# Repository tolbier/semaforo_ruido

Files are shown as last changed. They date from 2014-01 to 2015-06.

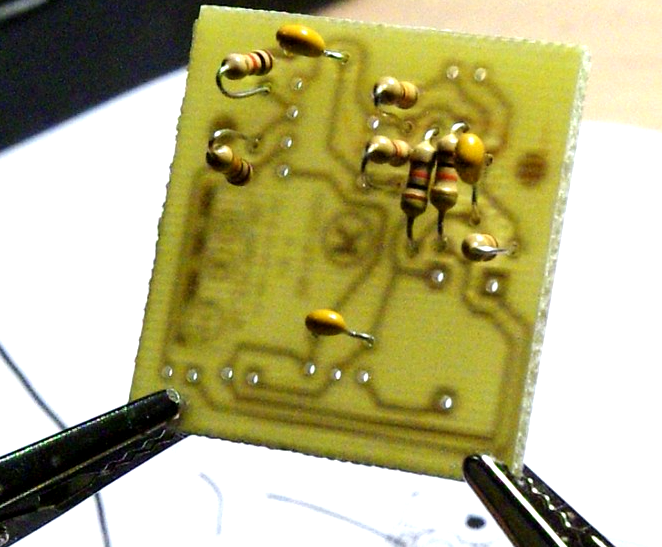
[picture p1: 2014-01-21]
tutoriales/images/wired_sensor_PCB_images/step12.png

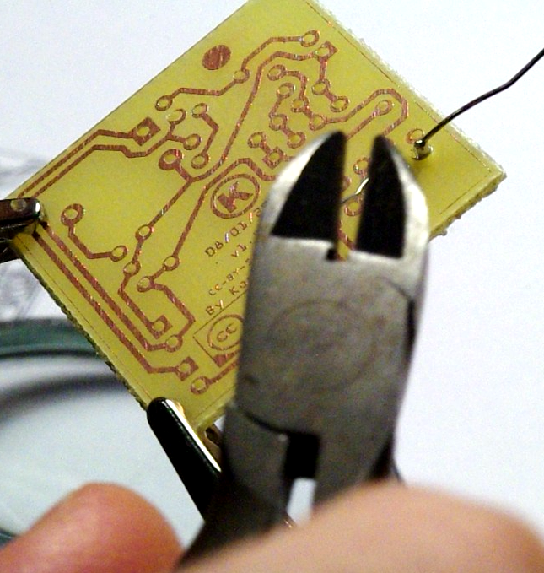
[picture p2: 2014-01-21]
tutoriales/images/wired_sensor_PCB_images/step6.png

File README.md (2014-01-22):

**para encontrar  ayuda y documentación, visita la [Wiki del proyecto](https://github.com/tolbier/semaforo_ruido/wiki)**

Semáforo de Ruido OpenSource
============================
El Semáforo de Ruido "OpenSource" es una instalación que capta el ruido de ambiente y activa un juego de 4 bloques de luces LED (en Verde, Amarillo, Naranja y Rojo) indicando la cantidad de ruido que hay en el ambiente.

Asimismo, se puede conectar un [MP3 Player Shield de SPARKFUN](https://www.sparkfun.com/products/10628), para reproducir sonidos al llegar a determinados niveles de ruido.



Un Proyecto Educativo
---------------------
Este proyecto tiene la aspiración de servir como herramienta educativa, con 2 funciones distintas:
* Servir como apoyo a los equipos docentes de los centros educativos en su tarea de lograr un espacio educativo libre de contaminación acústica.
* Como proyecto educativo en el área de Tecnología, que permite lograr conocimientos en las áreas de Electrónica y Programación Informática.

Licencia
--------
Los [esquemas y diseños PCB de las placas](https://github.com/tolbier/semaforo_ruido/tree/master/PCBs) están licenciados bajo [CC-BY-SA 3.0](http://creativecommons.org/licenses/by-sa/3.0/es/)

El [software](https://github.com/tolbier/semaforo_ruido/tree/master/src) está licenciado bajo [GNU/GPL v3.0](https://github.com/tolbier/semaforo_ruido/blob/master/src/LICENSE.txt)

Los [sonidos](https://github.com/tolbier/semaforo_ruido/tree/master/sonidos) incluídos en este proyecto están licenciados bajo [CC-BY-SA 3.0](http://creativecommons.org/licenses/by-sa/3.0/es/)

Todos los textos incluídos en este proyecto están licenciados bajo [CC-BY-SA 3.0](http://creativecommons.org/licenses/by-sa/3.0/es/)

**para encontrar  ayuda y documentación, visita la [Wiki del proyecto](https://github.com/tolbier/semaforo_ruido/wiki)**

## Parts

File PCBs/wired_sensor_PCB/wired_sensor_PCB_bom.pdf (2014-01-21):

# Bill of Materials: wired_sensor_PCB.fzz

/home/toyos/gitroot/semaforo_ruido_github/PCBs/wired_sensor_PCB/wired_sensor_PCB.fzz
martes, enero 21 2014, 22:05:40

# Assembly List

Label | Part Type | Properties
C1 | Ceramic Capacitor | paquete 200 mil [THT, multilayer]; capacitance 0.1µF; Voltaje 6.3V; part number 0.1uF
C2 | Electrolytic Capacitor | paquete 100 mil [THT, electrolytic]; capacitance 4.7µF; Voltaje 6.3V; part number 4.7uF
C3 | Electrolytic Capacitor | paquete 100 mil [THT, electrolytic]; capacitance 4.7µF; Voltaje 6.3V; part number 4.7uF
C4 | Ceramic Capacitor | paquete 200 mil [THT, multilayer]; capacitance 0.1µF; Voltaje 6.3V; part number 0.1uF
C5 | Ceramic Capacitor | paquete 200 mil [THT, multilayer]; capacitance 0.1µF; Voltaje 6.3V; part number 0.1uF
J1 | Generic male header - 3 pins | paquete THT; Tamaño del hoyo 0.8mm,0.5mm; row single; forma ♂ (male); pins 3; espacio entre pines 0.1in (2.54mm)
LM358 | LM 358 Dual Op-Amp | paquete DIP8 [THT]; part number LM358
MIC1 | Microphone
R1 | 1k Ω Resistor | paquete THT; tolerance ±5%; bands 4; Resistencia 1kΩ; power 250mW; espacio entre pines 400 mil; part number 1kΩ
Fritzing Bill of Materials | file:///usr2/gitroot/semaforo_ruido_github/PCBs/wired_sensor_PCB/...
1 de 3 | 21/01/14 22:28

Label | Part Type | Properties
R2 | 10k Ω Resistor | paquete THT; tolerance ±5%; bands 4; Resistencia 10kΩ; power 250mW; espacio entre pines 400 mil; part number 10K
R3 | 10k Ω Resistor | paquete THT; tolerance ±5%; bands 4; Resistencia 10kΩ; power 250mW; espacio entre pines 400 mil; part number 10K
R4 | 10k Ω Resistor | paquete THT; tolerance ±5%; bands 4; Resistencia 10kΩ; power 250mW; espacio entre pines 400 mil; part number 10K
R5 | 1k Ω Resistor | paquete THT; tolerance ±5%; bands 4; Resistencia 1kΩ; power 250mW; espacio entre pines 400 mil; part number 1kΩ
R6 | 10k Ω Resistor | paquete THT; tolerance ±5%; bands 4; Resistencia 10kΩ; power 250mW; espacio entre pines 400 mil; part number 10K
R7 | 10k Ω Resistor | paquete THT; tolerance ±5%; bands 4; Resistencia 10kΩ; power 250mW; espacio entre pines 400 mil; part number 10K
R8 | Trimmer Potentiometer | paquete THT; tamaño Trimmer - 12mm; track Linear; Tipo Trimmer Potentiometer; power 0.25W; máxima resistencia 5kΩ; part number 5kΩ

# Shopping List

Amount | Part Type | Properties
3 | Ceramic Capacitor | paquete 200 mil [THT, multilayer]; capacitance 0.1µF; Voltaje 6.3V; part number 0.1uF
2 | Electrolytic Capacitor | paquete 100 mil [THT, electrolytic]; capacitance 4.7µF; Voltaje 6.3V; part number 4.7uF
1 | Generic male header - 3 pins | paquete THT; Tamaño del hoyo 0.8mm,0.5mm; row single; forma ♂ (male); pins 3; espacio entre pines 0.1in (2.54mm)
1 | LM 358 Dual Op-Amp | paquete DIP8 [THT]; part number LM358

Amount | Part Type | Properties
1 | Microphone
2 | 1k Ω Resistor | paquete THT; tolerance ±5%; bands 4; Resistencia 1kΩ; power 250mW; espacio entre pines 400 mil; part number 1kΩ
5 | 10k Ω Resistor | paquete THT; tolerance ±5%; bands 4; Resistencia 10kΩ; power 250mW; espacio entre pines 400 mil; part number 10K
1 | Trimmer Potentiometer | paquete THT; tamaño Trimmer - 12mm; track Linear; Tipo Trimmer Potentiometer; power 0.25W; máxima resistencia 5kΩ; part number 5kΩ

Exported with Fritzing 0.8.5- http://fritzing.org

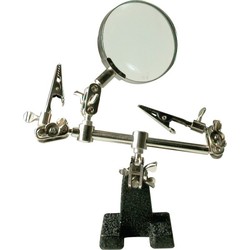
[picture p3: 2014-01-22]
tutoriales/images/material_necesario/soporte-lupa-pcb.jpg

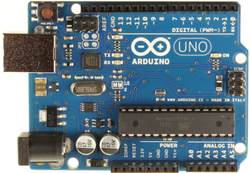
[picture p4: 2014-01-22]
tutoriales/images/material_necesario/ArduinoUno_R3.jpg

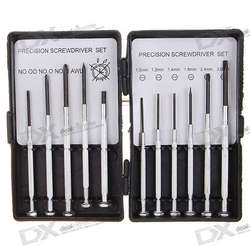
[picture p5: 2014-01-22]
tutoriales/images/material_necesario/juego_destornilladores_precision.jpg

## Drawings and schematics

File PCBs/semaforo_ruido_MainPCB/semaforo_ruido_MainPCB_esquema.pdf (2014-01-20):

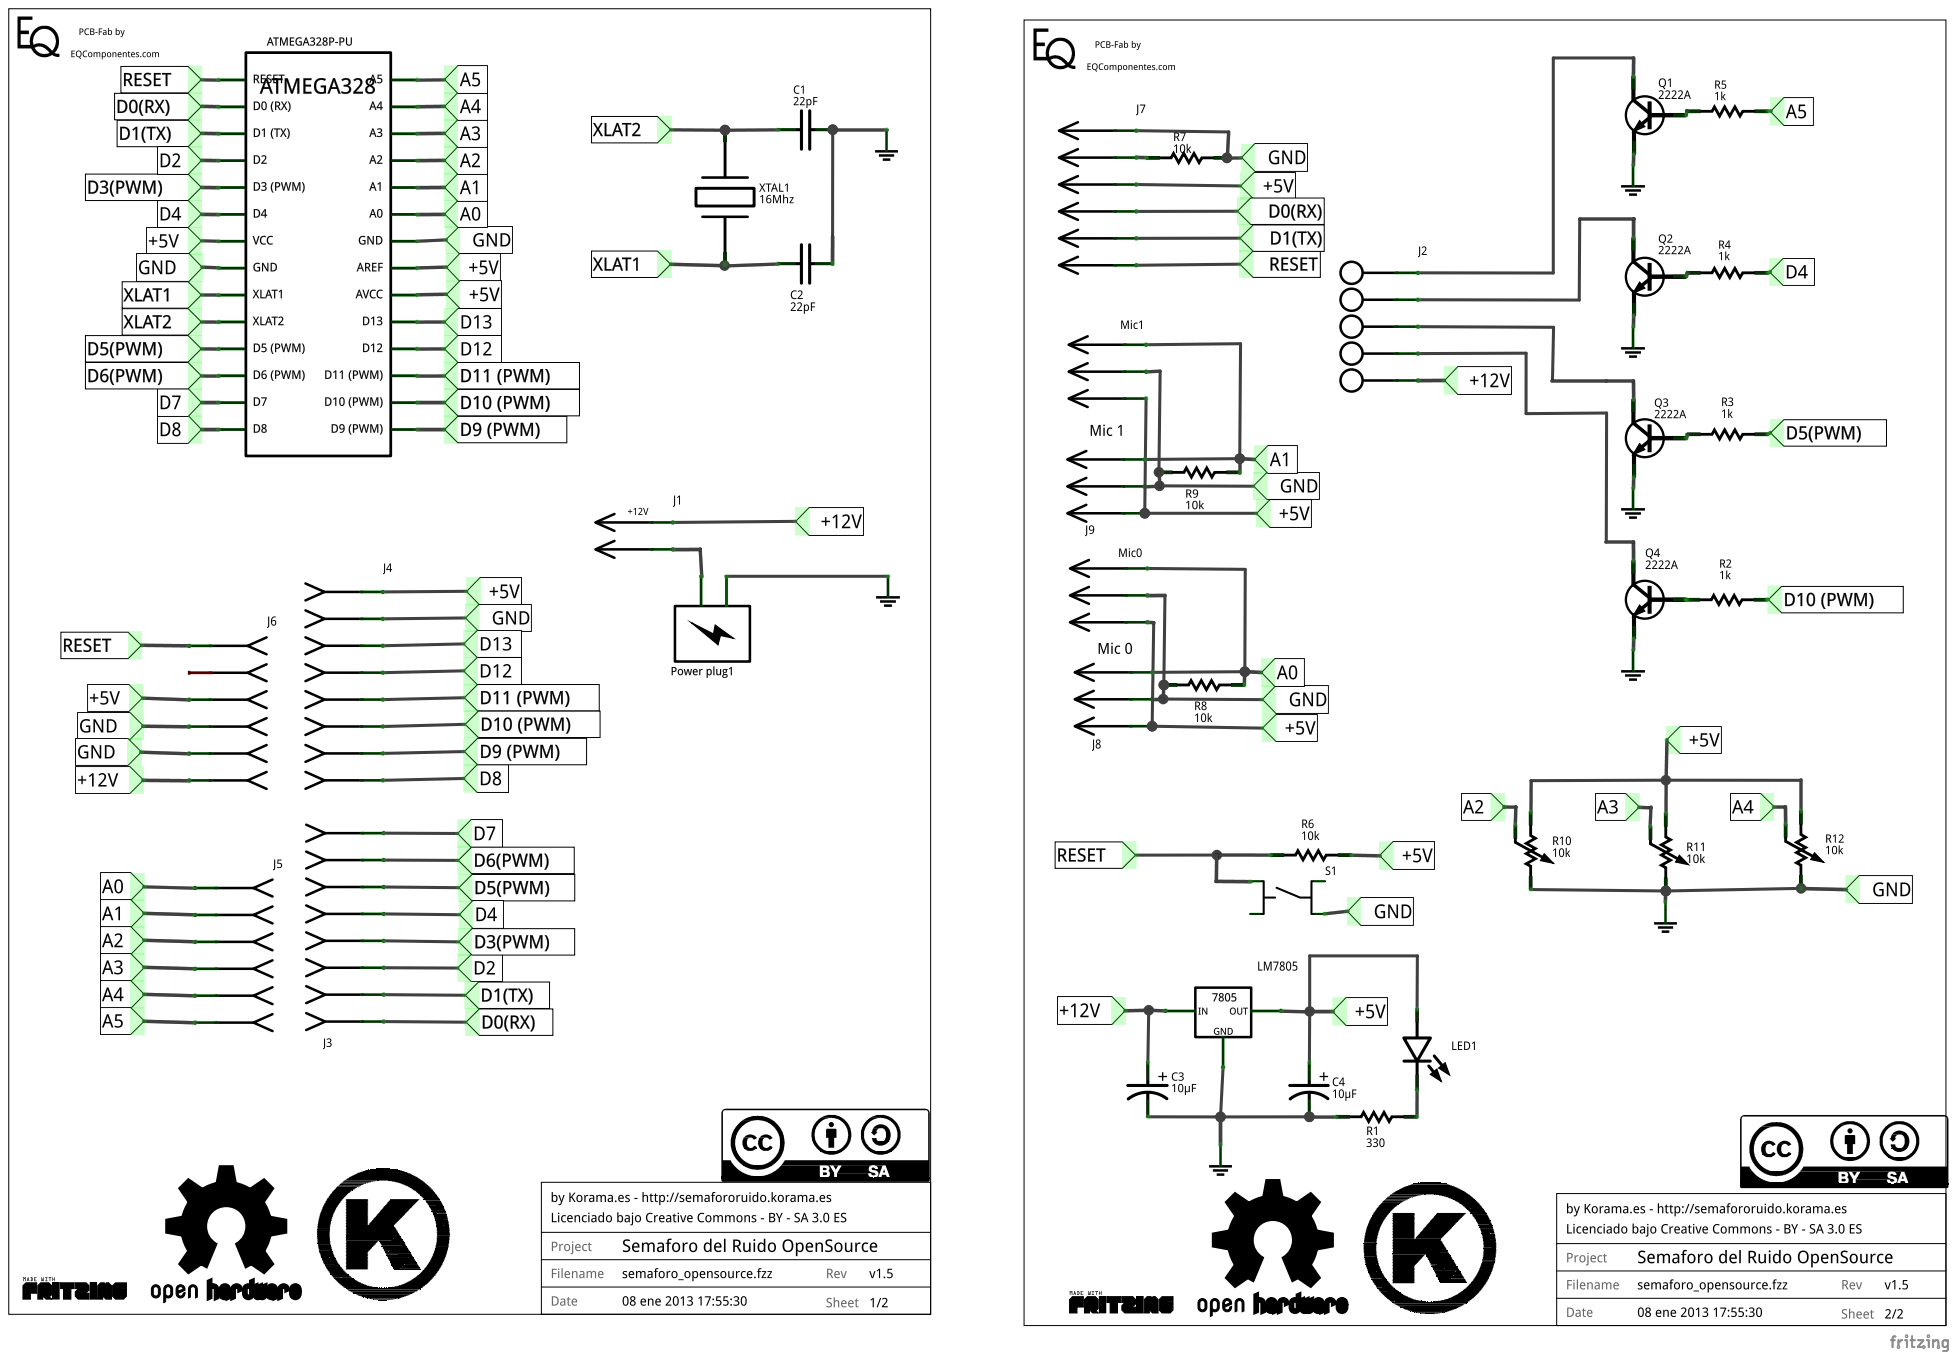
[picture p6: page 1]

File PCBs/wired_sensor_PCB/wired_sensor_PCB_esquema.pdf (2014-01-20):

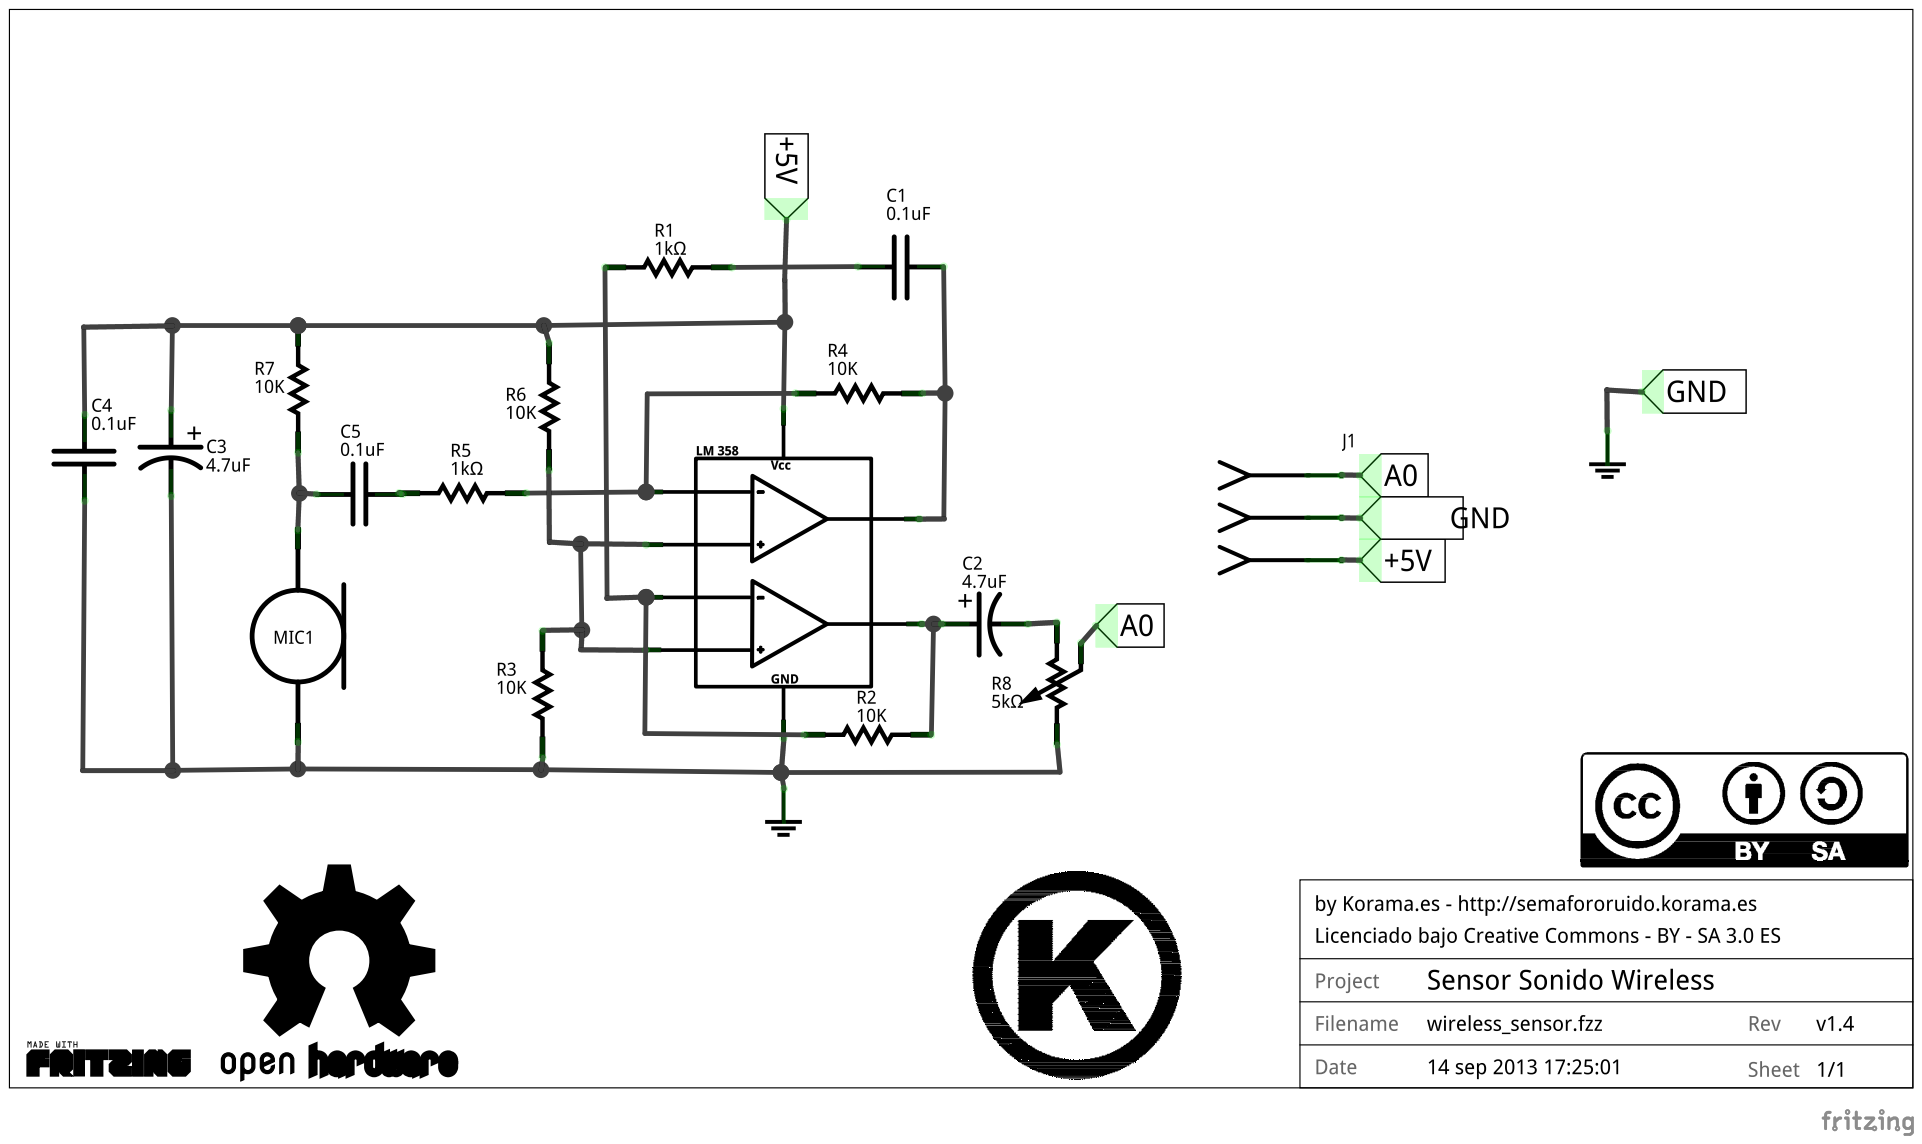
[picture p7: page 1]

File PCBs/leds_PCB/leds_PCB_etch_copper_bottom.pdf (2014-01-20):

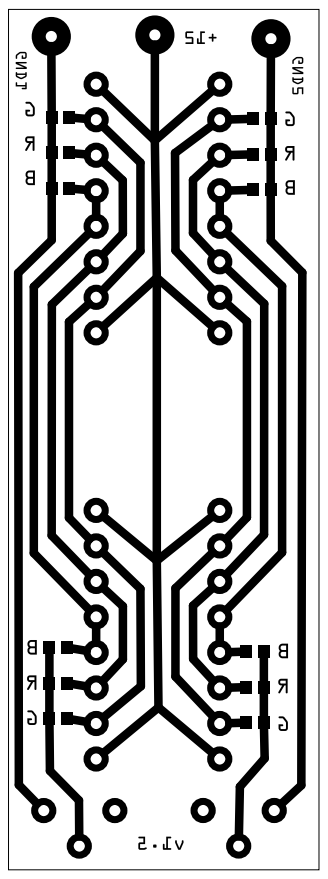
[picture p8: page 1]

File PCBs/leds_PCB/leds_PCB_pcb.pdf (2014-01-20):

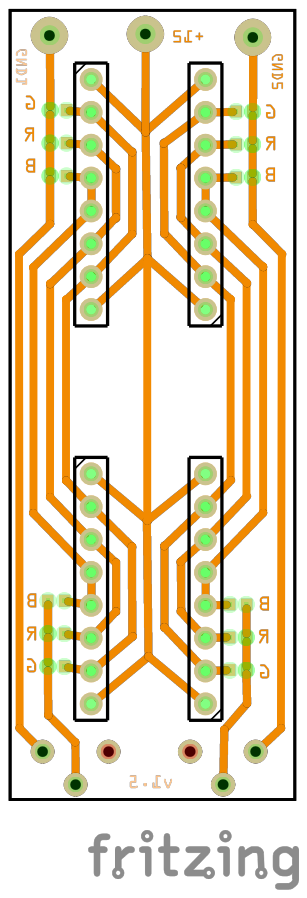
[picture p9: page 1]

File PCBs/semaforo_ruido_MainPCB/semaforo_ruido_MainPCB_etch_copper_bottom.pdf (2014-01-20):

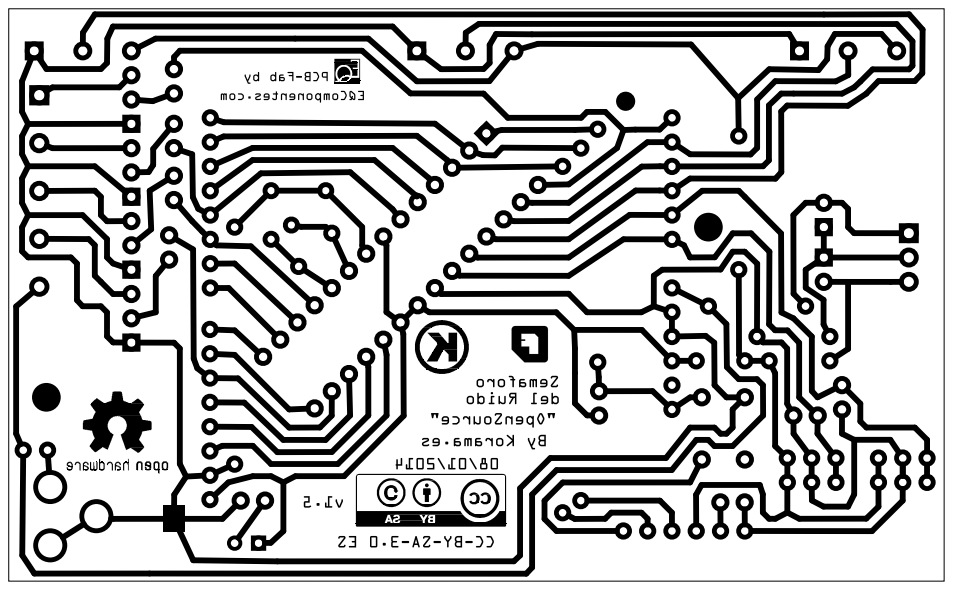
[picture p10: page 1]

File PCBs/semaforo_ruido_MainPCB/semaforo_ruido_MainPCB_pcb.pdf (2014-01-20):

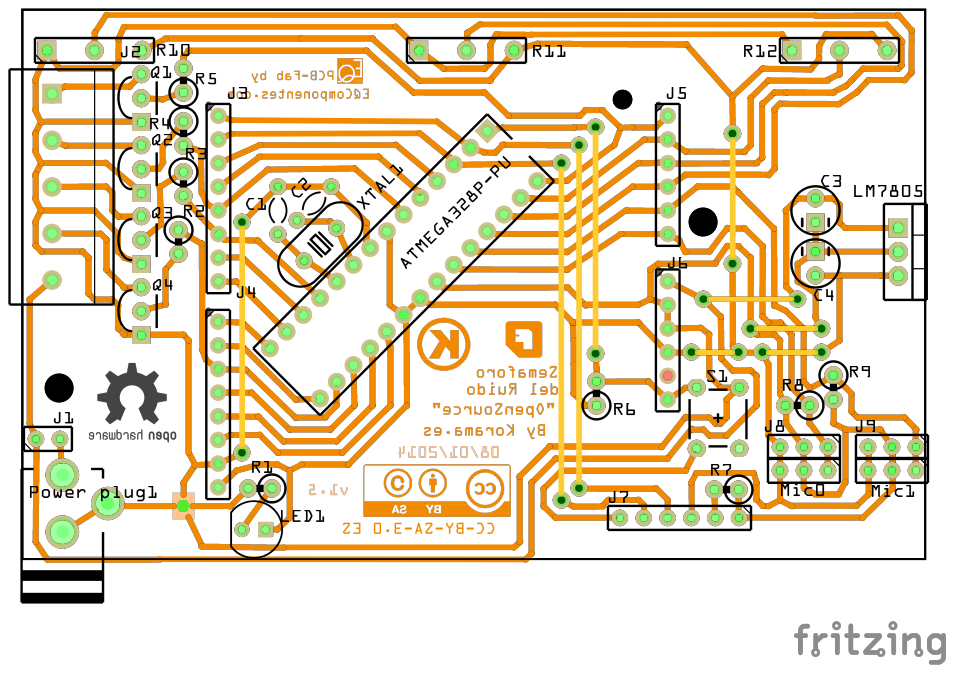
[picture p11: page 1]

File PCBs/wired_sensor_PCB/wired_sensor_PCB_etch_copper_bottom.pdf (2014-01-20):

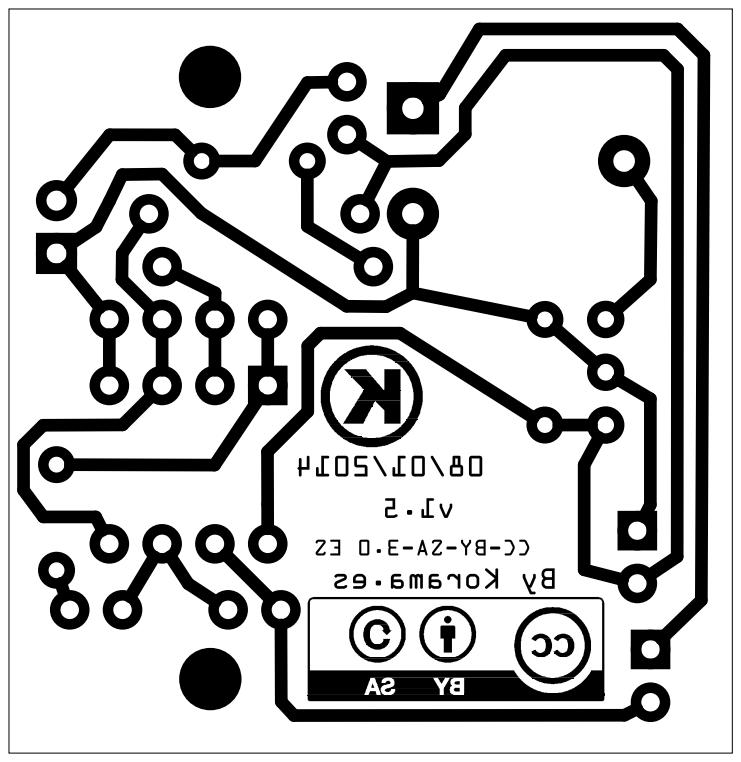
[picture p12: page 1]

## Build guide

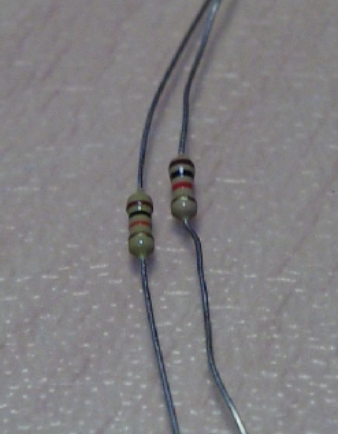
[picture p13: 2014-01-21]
tutoriales/images/wired_sensor_PCB_images/res_1k.png

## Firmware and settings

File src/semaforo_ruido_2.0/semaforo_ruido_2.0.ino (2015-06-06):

/*
 semaforo_ruido 
  ---------------
     This file is part of the Project  SEMAFORO_RUIDO OPEN_SOURCE
     - A Hardware+Software System to detect the noise levels and to sign them
     through a 4 colored LED system

    Copyright (C) 2014 Lluis Toyos

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
---------------    
    Archivo: semaforo_ruido.ino
    Fecha:20-ENE-2014
    Version: 0.80
    Autor: Lluis Toyos - info@korama.es - KORAMA Soluciones Digitales - http://korama.es
    
 -------------------
 */
#define delay_between_last_activation 8000 //tiempo en milisegundos de retardo desde la ultima activacion hasta que se pueda ejecutar la siguiente evaluacion
                         

#define numberOfLevels 4   //Numero de niveles de sonido
#define DOUBLE_ORANGE 0   // TO-DO: explicar 

int mic_pins[] = {A0, A1} ;              //Define en que pins estan conectadas las entradas de micro
int pot_pin[] = {A4,A2,A3};  //Define en que entradas estan las entradas de los 3 potenciometros
int rele[]={10,5,4,A5};       //Define los pins donde estan conectados los 4 reles




int threshold[]={0,20,40,60};
char buffer_formato_serial[50];

boolean levelsActivated[]={1,0,0,0}; //recoge el estado de los 4 reles 

unsigned long last_activate_time;

// Esta rutina se ejecuta al inicio, y cada vez que pulsamos RESET
void setup() {   
  Serial.begin(57600); //Use serial for debugging 
  Serial.println("MP3 Testing");  
  init_mp3_player();
 

  pinMode(A0, INPUT); 
  pinMode(A1, INPUT);
  init_led_handler();
}

// La rutina "loop" se ejecuta una y otra vez indefinidamente :
void loop() {

  //float amplitudeAvg=   getAmplitudeReading();
  float amplitudeReading =  getAmplitudeReadingMaxOnLastInterval();
  //Si ha pasado el tiempo delay_between_last_activation, evaluamos la AmplitudMedia
  evaluateAmplitude(amplitudeReading);

  //mostramos resultados en Serial
  printThresholds();
  printLevels();
  printSound(amplitudeReading);
  
}




void printSound(long amplitudeAvg){
  Serial.print(getNoiseDb(amplitudeAvg));
  Serial.println("dB");


}
void printThresholds(){
  for (int i=0;i<numberOfLevels;i++){
    Serial.print(getNoiseDb(threshold[i]));
    Serial.print("dB ");
  }
  
}

void printLevels(){
  for (int i=0;i<numberOfLevels;i++){
    Serial.print((levelsActivated[i])?"I":"O");
    Serial.print(" ");
  }

  
}

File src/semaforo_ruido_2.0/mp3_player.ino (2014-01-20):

/*
  mp3_player
 -----------------
     This file is part of the Project  SEMAFORO_RUIDO OPEN_SOURCE
     - A Hardware+Software System to detect the noise levels and to sign them
     through a 4 colored LED system

    Copyright (C) 2014 Lluis Toyos

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
---------------    
    Archivo: mp3_player.ino
    Fecha:20-ENE-2014
    Version: 0.80
    Autor: Lluis Toyos - info@korama.es - KORAMA Soluciones Digitales - http://korama.es
    NOTA:
        Este codigo esta basado en el programa MP3 Player de Nathan Seidle  - Sparkfun
        http://dlnmh9ip6v2uc.cloudfront.net/datasheets/Dev/Arduino/Shields/MP3_Player_Example.pde
        
        Su funcion es reproducir archivos MP3 a traves de la tarjeta MP3 Player Arduino Shield de Sparkfun
        Ver: https://www.sparkfun.com/products/10628
        
 -------------------
 */



#include <SPI.h>

//Add the SdFat Libraries
#include <SdFat.h>
#include <SdFatUtil.h> 
#include "Arduino.h"

//Create the variables to be used by SdFat Library
Sd2Card card;
SdVolume volume;
SdFile root;
SdFile track;

//This is the name of the file on the microSD card you would like to play
//Stick with normal 8.3 nomeclature. All lower-case works well.
//Note: you must name the tracks on the SD card with 001, 002, 003, etc. 
//For example, the code is expecting to play 'track002.mp3', not track2.mp3.
char trackName[] = "12345678.123";
int trackNumber = 1;

boolean mp3shield_present = false; 

char errorMsg[100]; //This is a generic array used for sprintf of error messages

#define TRUE  0
#define FALSE  1

#define MP3LOG 0           // Imprime en Serial algun registro de log durante la reproduccion MP3

//MP3 Player Shield pin mapping. See the schematic
#define MP3_XCS 6 //Control Chip Select Pin (for accessing SPI Control/Status registers)
#define MP3_XDCS 7 //Data Chip Select / BSYNC Pin
#define MP3_DREQ 2 //Data Request Pin: Player asks for more data
#define MP3_RESET 8 //Reset is active low
//Remember you have to edit the Sd2PinMap.h of the sdfatlib library to correct control the SD card.

//VS10xx SCI Registers
#define SCI_MODE 0x00
#define SCI_STATUS 0x01
#define SCI_BASS 0x02
#define SCI_CLOCKF 0x03
#define SCI_DECODE_TIME 0x04
#define SCI_AUDATA 0x05
#define SCI_WRAM 0x06
#define SCI_WRAMADDR 0x07
#define SCI_HDAT0 0x08
#define SCI_HDAT1 0x09
#define SCI_AIADDR 0x0A
#define SCI_VOL 0x0B
#define SCI_AICTRL0 0x0C
#define SCI_AICTRL1 0x0D
#define SCI_AICTRL2 0x0E
#define SCI_AICTRL3 0x0F


#define MaxNumberOfFilesPerLevel 10

int numberOfFilesPerLevel[numberOfLevels];

int init_mp3_player() {
  mp3shield_present = false; 
  pinMode(MP3_DREQ, INPUT);
  pinMode(MP3_XCS, OUTPUT);
  pinMode(MP3_XDCS, OUTPUT);
  pinMode(MP3_RESET, OUTPUT);
 
  digitalWrite(MP3_XCS, HIGH); //Deselect Control
  digitalWrite(MP3_XDCS, HIGH); //Deselect Data
  digitalWrite(MP3_RESET, LOW); //Put VS1053 into hardware reset



  //Setup SD card interface
  pinMode(9, OUTPUT);       //Pin 10 must be set as an output for the SD communication to work.
  if (!card.init(SPI_FULL_SPEED,9))  {
    Serial.println("Error: Card init"); //Initialize the SD card and configure the I/O pins.
    return (1);
  }
  if (!volume.init(&card)) {
    Serial.println("Error: Volume ini"); //Initialize a volume on the SD card.
    return (2);
  }
  if (!root.openRoot(&volume)){
    Serial.println("Error: Opening root"); //Open the root directory in the volume. 
    return (3);
  }

  //We have no need to setup SPI for VS1053 because this has already been done by the SDfatlib

  //From page 12 of datasheet, max SCI reads are CLKI/7. Input clock is 12.288MHz. 
  //Internal clock multiplier is 1.0x after power up. 
  //Therefore, max SPI speed is 1.75MHz. We will use 1MHz to be safe.
  SPI.setClockDivider(SPI_CLOCK_DIV16); //Set SPI bus speed to 1MHz (16MHz / 16 = 1MHz)
  SPI.transfer(0xFF); //Throw a dummy byte at the bus
  //Initialize VS1053 chip 
  delay(10);
  digitalWrite(MP3_RESET, HIGH); //Bring up VS1053
  //delay(10); //We don't need this delay because any register changes will check for a high DREQ

  // Mp3SetVolume(0, 0); //Set initial volume (20 = -10dB) LOUD
  //Mp3SetVolume(40, 40); //Set initial volume (20 = -10dB) Manageable
  //Mp3SetVolume(27, 127); //Set initial volume (20 = -10dB) More quiet

  //Let's check the status of the VS1053
  int MP3Mode = Mp3ReadRegister(SCI_MODE);
  int MP3Status = Mp3ReadRegister(SCI_STATUS);
  int MP3Clock = Mp3ReadRegister(SCI_CLOCKF);

  Serial.print("SCI_Mode (0x4800) = 0x");
  Serial.println(MP3Mode, HEX);

  Serial.print("SCI_Status (0x48) = 0x");
  Serial.println(MP3Status, HEX);

  int vsVersion = (MP3Status >> 4) & 0x000F; //Mask out only the four version bits
  Serial.print("VS Version (VS1053 is 4) = ");
  Serial.println(vsVersion, DEC); //The 1053B should respond with 4. VS1001 = 0, VS1011 = 1, VS1002 = 2, VS1003 = 3

  Serial.print("SCI_ClockF = 0x");
  Serial.println(MP3Clock, HEX);

  //Now that we have the VS1053 up and running, increase the internal clock multiplier and up our SPI rate
  Mp3WriteRegister(SCI_CLOCKF, 0x60, 0x00); //Set multiplier to 3.0x

  //From page 12 of datasheet, max SCI reads are CLKI/7. Input clock is 12.288MHz. 
  //Internal clock multiplier is now 3x.
  //Therefore, max SPI speed is 5MHz. 4MHz will be safe.
  SPI.setClockDivider(SPI_CLOCK_DIV4); //Set SPI bus speed to 4MHz (16MHz / 4 = 4MHz)

  MP3Clock = Mp3ReadRegister(SCI_CLOCKF);
  Serial.print("SCI_ClockF = 0x");
  Serial.println(MP3Clock, HEX);

  init_numberOfFilesPerLevel();
  
  mp3shield_present=true;
  return (0);
  //MP3 IC setup complete
}


//#define MaxNumberOfFilesPerLevel 10
//int numberOfFilesPerLevel[numberOfLevels];
void init_numberOfFilesPerLevel(){
   //Recorrer los 4 niveles
   Serial.print("numberOfFilesPerLevel: ");
   for (int i =0 ; i<numberOfLevels; i++){
     //para cada nivel, averiguar cual es el numero de archivos que hay disponibles, 
     //y guardarlo en numberOfFilesPerLevel
     numberOfFilesPerLevel[i]= getNumberOfFilesPerLevel(i);
     Serial.print(numberOfFilesPerLevel[i]);
     Serial.print(" ");
   }
   Serial.println();
}

int getNumberOfFilesPerLevel(int level){
  int i=0;
  boolean encontrado=false;
  while (i<MaxNumberOfFilesPerLevel && ! encontrado){
    encontrado = ! existsFileLevelNumber(level,i);
    i++;
  }
  if (encontrado){
    i--;
  }
  //Devuelve el numero de files encontrados
  return i;
  
}

boolean existsFileLevelNumber(int level,int numFile){
  boolean retorno;
  sprintf(trackName, "lev%1d_%03d.mp3", level,numFile);
  retorno =track.open(&root, trackName, O_READ) ; //Open the file in read mode.
  if (retorno) track.close();
  return retorno;
}
void playLevelWarningMp3(int level){
  
//  sprintf(trackName, "lev%d_%03d.mp3", level, trackNumber);
}
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

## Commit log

2013-03-18 Añadido el esquema
    [Esquema Semaforo Ruido.fzz]
2013-03-20 Incluído texto GNUGPL en esquema y labels de potenciometros
    [Esquema Semaforo Ruido.fzz]
2013-03-20 Modificaciones menores en README y Esquema
    [Esquema Semaforo Ruido.fzz]
2014-01-20 subimos nuevo código para la v0.80
2014-01-20 añadidos PCBs Semaforo, Sensor y LED
    [Esquema Semaforo Ruido.fzz, leds_PCB.fzz, semaforo_ruido_MainPCB.fzz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]
2014-01-20 movidos sonidos de nivel 1 y 2 a extras
2014-01-20 movido el código a /src
2014-01-20 actualizados los fuentes y dividido el Readme.md
2014-01-20 actualizado el texto del GNUJ GPL
2014-01-20 añadidos esquemas PCBs
2014-01-21 añadidas las imágenes en JPG de las PCB
2014-01-21 añadidas imágenes wired_sensor_PCB
2014-01-21 añadidos thumbs de wired sensor
2014-01-21 mejoradas imágenes de wired_sensor
2014-01-21 añadido wired_sensor_PCB_bom.html
2014-01-21 modificado el poste polar del wired_sensor_PCB.fzz, de hembra a macho
    [wired_sensor_PCB.fzz]
2014-01-21 convertido el wired_sensor_PCB_bom de html a pdf
2014-01-22 cambiado el readme
2014-01-22 añadida la guía del inventor de Reflexiona
2014-01-22 actualizada guia del inventor de 2.0 a 3.0
2014-01-22 subidas imágenes de material necesario
2014-01-22 añadido thumb de tabla resistencias
2014-01-22 añadido thumb de step13

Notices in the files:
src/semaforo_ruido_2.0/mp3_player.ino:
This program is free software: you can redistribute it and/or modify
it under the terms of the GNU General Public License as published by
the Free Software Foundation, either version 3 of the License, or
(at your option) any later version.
